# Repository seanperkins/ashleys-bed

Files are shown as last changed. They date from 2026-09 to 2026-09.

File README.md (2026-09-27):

# Ashley’s Murphy bed

Build guide: https://seanperkins.github.io/ashleys-bed/

Current design: Rockler I-Semble horizontal queen bed with one room-facing left bookcase and drawer. Overall carcass: **116¾ W × 64 H × 16 D inches**. The right cabinet is removed.

## Release status

The native models, drawings, parts list and nominal sheet layouts are design-review deliverables. **No machine-ready CAM or G-code is released.** Plywood and cutters have not been purchased. Final stock thickness, bookcase joinery, hardware, workholding, tools and the shop-approved post/profile must be resolved before machining.

Follow the complete [Rockler horizontal-bed instructions](https://go.rockler.com/tech/horizontal-murphy-bed-inst-25.pdf) and [HackRVA Avid PRO6096 requirements](https://wiki.hackrva.org/index.php/Avid_PRO6096). Hardware and motion in CAD remain representative. Hidden wall brackets remain required; both headboards and all specified anchors are retained.

## Fit allowances in the current design

These are built into the Fusion model, cut list, DXFs and drawings. They assume nominal stock; recheck them once the plywood is measured.

- **Adjustable shelves 1–3:** 15¾ × 28⅜ in, giving 1/16 in clearance per side between the bookcase's 28½ in sides so they can be placed on pins. The fixed shelf above the drawer stays 28½ in.
- **Bookcase back:** ¼ × 28 7/16 × 59 15/16 in, giving 1/32 in clearance per edge where it sits inside the carcass. Resize it if the back is set into rabbets or grooves instead.
- **Drawer box:** 27½ in wide in a 28½ in opening, ½ in per side for side-mount slides. Confirm against the chosen slide.
- **Gas springs (model only):** 14 in cylinder and 13½ in rod, chosen to span the modeled mounts. They are not Rockler's specification.

## Build the website

The website builder uses Python 3.10+ standard library only. No Node packages, API keys or backend are needed.

```sh
python3 site/build.py
python3 -m http.server 8047 --directory site/_site
```

Open http://localhost:8047. The build checks local links, anchors, duplicate IDs, required downloads and the current model revision. Page links are relative, so the guide works under the GitHub Pages project path.

- `site/content/`: page-specific instructions.
- `site/assets/`: responsive/print styles and browser-local checklist/worksheet behavior.
- `site/assets/vendor/`: pinned, self-hosted `<model-viewer>` 4.3.1 for the overview page's 3D viewer. No third-party requests.
- `site/build.py`: page shell, live BOM table, download index and explicit public-file allowlist.
- `output/`: current verified models and generated project documents.
- `.github/workflows/pages.yml`: builds and deploys the guide on pushes to `main` or manual dispatch.

Checklist and worksheet values remain in the reader’s browser. “Export my notes” downloads them; they are not sent to GitHub or a server. Printed worksheets expand full field values and disclosure notes. Checking boxes does not release machining.

## Update the design documents

1. Run `MurphyBedQueen/MurphyBedQueen.py` inside Autodesk Fusion. It creates a new design and exports open/closed F3D and STEP files, native previews, the wood cut list, drawing-body bounds and a build report. On success, `output/build-result.json` reports `"status": "exported; requires visual review of saved previews"` and an empty `timelineWarnings` list. Use any one of these:
   - **Fusion UI:** Utilities → Scripts and Add-Ins → Scripts → **MurphyBedQueen** → Run.
   - **Fusion MCP add-in (no clicks):** with the `AutodeskFusionMCP` add-in running, Fusion serves MCP at `http://127.0.0.1:8765/mcp`. Initialize a session, then call its `execute_python` tool with:

     ```python
     import importlib.util
     from pathlib import Path
     path = Path('/Users/sean/sites/ashleys-bed/MurphyBedQueen/MurphyBedQueen.py')
     spec = importlib.util.spec_from_file_location('ashleys_bed_model', path)
     module = importlib.util.module_from_spec(spec)
     spec.loader.exec_module(module)
     module.run({})
     ```

     A full run takes about 15 seconds. The script opens no dialogs, so it does not block Fusion's main thread.
   - **Startup add-in:** the `AshleysBedStartup` add-in in Fusion's `API/AddIns` folder runs the script once when Fusion starts if its manifest has `"runOnStartup": true`. It resets the flag to `false` before running and records `started`, `finished` or `failed` in `output/startup-trigger.json`.
2. Reopen both saved Fusion archives and verify the intended cabinet count/position, bed endpoints, required hidden references and timeline health. Review native previews; do not treat a successful export as a fabrication release.
3. Generate the nominal layouts and design-review drawings:

   ```sh
   python3 MurphyBedQueen/generate_cut_layouts.py
   python3 MurphyBedQueen/generate_drawings.py
   ```

   Then build the GLB files used by the site's 3D viewer (needs `pip install cascadio trimesh`). It writes static closed/open models and an animated open/close model. It fails if any part does not match the bed and leg joints in `MurphyBedQueen.py`, if the STEP gas-spring mounts moved, or if the swing puts the leg through the mattress or below the floor:

   ```sh
   python3 MurphyBedQueen/export_web_models.py
   ```

   The cut-layout generator uses the standard library and rejects unexpected parts or dimensions. When a part size changes on purpose, update its approved size in `PART_SPECS` (and its sheet placement in `SHEET_PLAN` if it no longer fits) in `generate_cut_layouts.py`. The drawing generator requires Pillow and the macOS Helvetica font; it consumes native Fusion body bounds, not guessed image dimensions. Site deployment does not regenerate CAD or require Pillow.
4. Update purchasing instructions and the BOM when the design changes. Then regenerate the one-page printable store list, `output/store-shopping-list.pdf`, with `python3 MurphyBedQueen/generate_store_list.py` (requires Pillow and the macOS Helvetica font). It takes quantities from the BOM and fails if a BOM item is added or removed without updating its `ITEMS` table, or if the list no longer fits on one page. Recheck all sheet quantities, hardware requirements and finish allowances. Refresh the design-review ZIP from the matching current outputs; do not include old revisions or prior budgets. To rebuild it with the same file list:

   ```sh
   cd output && unzip -Z1 ashleys-bed-design-review.zip > /tmp/zip-list.txt \
     && rm -f /tmp/review.zip && zip -q -X /tmp/review.zip -@ < /tmp/zip-list.txt \
     && mv /tmp/review.zip ashleys-bed-design-review.zip
   ```
5. Run the website build, inspect desktop/mobile pages, exercise saved checklists/search/note export, and print a worksheet with long notes before publishing.

## Publication boundary

The Pages artifact contains six guide pages, static assets and explicitly selected current downloads. Old two-cabinet budgets, media and local revision archives are excluded. The manufacturer PDF is linked at its official source rather than republished. Local `references/`, `revisions/` and `output/previous-*` directories are ignored.

Historical Richmond supplier leads are dated and are not current prices or stock confirmations. No current project total or mattress purchase price is represented.

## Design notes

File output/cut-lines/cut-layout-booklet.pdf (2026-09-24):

# ASHLEY'S MURPHY BED + LEFT BOOKCASE

## S01 | 3/4 in stock | 48 x 96 in | 4 parts

### NOMINAL PLANNING OUTLINES - NOT CNC-READY

3/4 in edge margin | 1/2 in minimum part gap | Grain parallel to every part length
M03 | M04

L16
L05

Stock width 48 in / length 96 in Origin (0,0): lower-left stock corner

GRAIN +Y

### PARTS ON THIS SHEET

Dimensions in inches: width x length X / Y = lower-left nominal outline

M03 Bed top
16 x 85 1/4 in
Finished thickness: 3/4 in X 0.75 / Y 0.75

M04 Bed bottom
16 x 85 1/4 in
Finished thickness: 3/4 in X 17.25 / Y 0.75

L16 Drawer face
10 1/2 x 28 1/4 in
Finished thickness: 3/4 in X 33.75 / Y 0.75

L05 Recessed plinth
2 1/2 x 28 1/2 in
Finished thickness: 3/4 in X 44.75 / Y 0.75

SHARED STOCK
Left shelf
Main cabinet

Drawing scale: 1:14.4
US Letter; print Actual Size / 100%.
Use written dimensions, not a paper template.

M07 on S02: mill the 3/4 in stock blank to 5/8 in finished thickness.
Shelf/back fit included; finalize joinery, slides and measured stock before cutting.
No cutter compensation, holes, pockets or G-code. Confirm cutter, workholding and post. DXF: inches, closed PART_OUTLINES. Stock/margin/grain/labels are reference only.

SVG: full scale in inches, including a separate note area. PDF: reduced-scale planning booklet.

27 parts | 6 full 3/4 sheets + 1 half-inch 24x48 panel + 1 full quarter-inch sheet | No spare

## S02 | 3/4 in stock | 48 x 96 in | 3 parts

### NOMINAL PLANNING OUTLINES - NOT CNC-READY

3/4 in edge margin | 1/2 in minimum part gap | Grain parallel to every part length
M05 | M06

M07

Stock width 48 in / length 96 in Origin (0,0): lower-left stock corner

GRAIN +Y

### PARTS ON THIS SHEET

Dimensions in inches: width x length X / Y = lower-left nominal outline

M05 Upper headboard
16 x 85 1/4 in
Finished thickness: 3/4 in X 0.75 / Y 0.75

M06 Lower headboard
16 x 85 1/4 in
Finished thickness: 3/4 in X 17.25 / Y 0.75

M07 Permanent stop
3 x 56 in
Finished thickness: 5/8 in X 33.75 / Y 0.75

DEDICATED STOCK
Main cabinet

Drawing scale: 1:14.4
US Letter; print Actual Size / 100%.
Use written dimensions, not a paper template.

M07 on S02: mill the 3/4 in stock blank to 5/8 in finished thickness.
Shelf/back fit included; finalize joinery, slides and measured stock before cutting.
No cutter compensation, holes, pockets or G-code. Confirm cutter, workholding and post. DXF: inches, closed PART_OUTLINES. Stock/margin/grain/labels are reference only.

## S03 | 3/4 in stock | 48 x 96 in | 4 parts

### NOMINAL PLANNING OUTLINES - NOT CNC-READY

3/4 in edge margin | 1/2 in minimum part gap | Grain parallel to every part length
M01 | M02
L03 | L04

Stock width 48 in / length 96 in Origin (0,0): lower-left stock corner

GRAIN +Y

### PARTS ON THIS SHEET

Dimensions in inches: width x length X / Y = lower-left nominal outline

M01 Bed right side
16 x 64 in
Finished thickness: 3/4 in X 0.75 / Y 0.75

M02 Bed left side
16 x 64 in
Finished thickness: 3/4 in X 17.25 / Y 0.75

L03 Left bookcase top
16 x 28 1/2 in
Finished thickness: 3/4 in
X 0.75 / Y 65.25

L04 Left bookcase bottom
16 x 28 1/2 in
Finished thickness: 3/4 in
X 17.25 / Y 65.25

SHARED STOCK
Left shelf
Main cabinet

Drawing scale: 1:14.4
US Letter; print Actual Size / 100%.
Use written dimensions, not a paper template.

M07 on S02: mill the 3/4 in stock blank to 5/8 in finished thickness.
Shelf/back fit included; finalize joinery, slides and measured stock before cutting.
No cutter compensation, holes, pockets or G-code. Confirm cutter, workholding and post. DXF: inches, closed PART_OUTLINES. Stock/margin/grain/labels are reference only.

## S04 | 3/4 in stock | 48 x 96 in | 4 parts

### NOMINAL PLANNING OUTLINES - NOT CNC-READY

3/4 in edge margin | 1/2 in minimum part gap | Grain parallel to every part length
L01 | L02
L07 | L08

Stock width 48 in / length 96 in Origin (0,0): lower-left stock corner

GRAIN +Y

### PARTS ON THIS SHEET

Dimensions in inches: width x length X / Y = lower-left nominal outline

L01 Left bookcase left side
16 x 64 in
Finished thickness: 3/4 in
X 0.75 / Y 0.75

L02 Left bookcase right side 16 x 64 in
Finished thickness: 3/4 in
X 17.25 / Y 0.75

L07 Shelf above drawer
15 3/4 x 28 1/2 in
Finished thickness: 3/4 in
X 0.75 / Y 65.25

L08 Adjustable shelf 1
15 3/4 x 28 3/8 in
Finished thickness: 3/4 in X 17.25 / Y 65.25

DEDICATED STOCK
Left shelf

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

## S05 | 3/4 in stock | 48 x 96 in | 3 parts

### NOMINAL PLANNING OUTLINES - NOT CNC-READY

3/4 in edge margin | 1/2 in minimum part gap | Grain parallel to every part length
M08 | M09

L09

Stock width 48 in / length 96 in Origin (0,0): lower-left stock corner

GRAIN +Y

### PARTS ON THIS SHEET

Dimensions in inches: width x length X / Y = lower-left nominal outline

M08 Door panel 5.1
21 1/8 x 61 13/16 in
Finished thickness: 3/4 in X 0.75 / Y 0.75

M09 Door panel 5.2
21 1/8 x 61 13/16 in
Finished thickness: 3/4 in X 22.375 / Y 0.75

L09 Adjustable shelf 2
15 3/4 x 28 3/8 in
Finished thickness: 3/4 in X 0.75 / Y 63.0625

SHARED STOCK
Left shelf
Main cabinet

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

## S06 | 3/4 in stock | 48 x 96 in | 3 parts

### NOMINAL PLANNING OUTLINES - NOT CNC-READY

3/4 in edge margin | 1/2 in minimum part gap | Grain parallel to every part length
M10 | M11

L10

Stock width 48 in / length 96 in Origin (0,0): lower-left stock corner

GRAIN +Y

### PARTS ON THIS SHEET

Dimensions in inches: width x length X / Y = lower-left nominal outline

M10 Door panel 5.3
21 1/8 x 61 13/16 in
Finished thickness: 3/4 in X 0.75 / Y 0.75

M11 Door panel 5.4
21 1/8 x 61 13/16 in
Finished thickness: 3/4 in X 22.375 / Y 0.75

L10 Adjustable shelf 3
15 3/4 x 28 3/8 in
Finished thickness: 3/4 in X 0.75 / Y 63.0625

SHARED STOCK
Left shelf
Main cabinet

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

## S07 | 1/2 in stock | 24 x 48 in | 4 parts

### NOMINAL PLANNING OUTLINES - NOT CNC-READY

3/4 in edge margin | 1/2 in minimum part gap | Grain parallel to every part length
L13 | L14
L11 | L12

Stock width 24 in / length 48 in Origin (0,0): lower-left stock corner

GRAIN +Y

### PARTS ON THIS SHEET

Dimensions in inches: width x length X / Y = lower-left nominal outline

L13 Drawer back
8 x 26 1/2 in
Finished thickness: 1/2 in X 0.75 / Y 0.75

L14 Drawer inner front
8 x 26 1/2 in
Finished thickness: 1/2 in X 9.25 / Y 0.75

L11 Drawer left side
8 x 14 in
Finished thickness: 1/2 in X 0.75 / Y 27.75

L12 Drawer right side
8 x 14 in
Finished thickness: 1/2 in X 9.25 / Y 27.75

DEDICATED STOCK
Left shelf

Drawing scale: 1:7.2
US Letter; print Actual Size / 100%.
Use written dimensions, not a paper template.

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

## S08 | 1/4 in stock | 48 x 96 in | 2 parts

### NOMINAL PLANNING OUTLINES - NOT CNC-READY

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

L06

L15

Stock width 48 in / length 96 in Origin (0,0): lower-left stock corner

GRAIN +Y

### PARTS ON THIS SHEET

Dimensions in inches: width x length X / Y = lower-left nominal outline

L06 Bookcase back
28 7/16 x 59 15/16 in
Finished thickness: 1/4 in X 0.75 / Y 0.75

L15 Drawer bottom
14 x 27 1/2 in
Finished thickness: 1/4 in X 29.75 / Y 0.75

DEDICATED STOCK
Left shelf

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

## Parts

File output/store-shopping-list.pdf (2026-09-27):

# Ashley's Murphy bed - store shopping list

Queen horizontal bed (86-3/4 in) + left bookcase (30 in). Check each box as it goes in the cart.
Planning quantities from the project bill of materials. Confirm the slide model, pull centers and shelf pins against the build guide before buying hardware.
LUMBER - buy full sheets; do not have the store cut them (the CNC layout needs full sheets)
6 sheets 3/4 in plywood, 4 x 8 ft | Cabinet-grade, veneer core. No MDF, particleboard or melamine.
1 project panel 1/2 in plywood, 2 x 4 ft | For the drawer box. Cabinet-grade.
1 sheet 1/4 in plywood, 4 x 8 ft | Bookcase back and drawer bottom.
HARDWARE
1 pair 14 in drawer slides | Full-extension, side-mount, ball-bearing; needs 1/2 in per side.
20 shelf pins, 5 mm | Steel, flat or spoon style. 12 needed + spares.
3 black bar pulls, about 6 in centers | Two for the bed doors, one for the drawer. Check screws are included.
1 furniture anti-tip kit | For the bookcase, rated for wood studs. Extra to the bed anchors.
Optional: 4 connector bolt sets | Joins bed and bookcase sides (about 1-1/2 in total). Not a wall anchor.
FASTENERS, GLUE & SHIMS
100 #8 x 2 in wood screws | Wood or cabinet screws, not drywall screws.
50 fluted dowels, 3/8 x 1-1/2 in | Hardwood.
25 #8 x 1-1/4 in wood screws | Permanent stop.
50 #6 x 1-1/4 in wood screws | Drawer box corners.
25 #8 x 1 in washer-head wood screws | Drawer face.
100 #6 x 3/4 in pan or washer-head screws | Bookcase back and drawer bottom.
1 bottle wood glue, 16 oz | Interior PVA.
1 small bottle removable threadlocker | Blue / removable strength.
1 pack hard cabinet shims | Plastic or composite, not soft wood.
PAINT & FINISHING
1 quart paintable wood filler | Sandable; for plywood edges and screw holes.
1 gallon primer | Suited to plywood and the enamel you choose.
2 gallons navy cabinet enamel | Match #182B49; check a dried sample first.
Optional: 1 quart clear water-based finish | Drawer box only.
3 packs sandpaper: 120, 180, 220 grit | Match your sander.
Painting supplies | Brushes/rollers, tray liners, masking tape, drop cloth, rags.
TOOLS - only if you do not already have them
8 mm Allen key | Drives the threaded inserts. The kit does not include this size.
3/8 in doweling jig | For the cabinet dowel joints.
Drill bits | 5/64, 1/8, 5/32, 3/16, 13/64, 5/16, 3/8 and 27/64 in, plus a #8 countersink.
Clamps, square, level, stud finder | For glue-up and installation. Do not use an impact driver.
NOT FROM THIS STORE
Rockler I-Semble HORIZONTAL QUEEN bed kit Rockler only. Not a vertical kit.
Queen mattress (you supply) | 60 x 80 in, 10 in thick max, 132 lb max, not foam or very light.
CNC cutters and machine time | Through HackRVA; not a store purchase.

BEFORE CHECKOUT
Sheets lie flat, faces have no dents or splits, and edges show no large voids.
Measure one sheet of each thickness with calipers and write it down; it sets final joinery and fit. Pulls and slides: check the screws are in the package before leaving.

Full details: seanperkins.github.io/ashleys-bed/purchase.html

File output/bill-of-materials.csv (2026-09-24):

Group | Item | Buy_quantity | Unit | Specification | Where_used | Quantity_basis | Notes | Source
Main materials | Rockler I-Semble horizontal queen steel-frame Murphy bed kit | 1 | complete kit | HORIZONTAL mount; QUEEN 60 x 80 mattress; steel platform with 40 wood slats | Center bed | One kit | Exact horizontal-queen SKU not verified; do not substitute a vertical kit. Included hardware appears in the separate kit-inventory CSV. Confirm the noted manual discrepancies with Rockler. | https://go.rockler.com/tech/horizontal-murphy-bed-inst-25.pdf pp4-5
Main materials | 3/4-inch cabinet-grade plywood | 6 | 48 x 96 inch sheets | Veneer-core cabinet-grade plywood; no MDF/particleboard core | Main bed cabinet and four bed fronts; LEFT cabinet carcass, shelves and drawer face | Shared-sheet purchasing layout; 21 stock pieces total | 20 finished 3/4-inch pieces plus one stop blank to mill to 5/8 inch. Main: 11 stock pieces from S01/S02/S03/S05/S06; S02 dedicated. Left: 10 stock pieces from S01/S03/S04/S05/S06; S04 dedicated. Shared: S01/S03/S05/S06. Buy S01-S06 once total. 3/4-inch sheet-edge margins and 1/2-inch gaps; grain follows Length_in. No spare full sheet or minimum-sheet claim. See plywood-by-project.csv for every piece. | Project bed-plus-left-cabinet design
Main materials | 1/2-inch drawer-box plywood | 1 | 24 x 48 inch project panel | Cabinet-grade plywood; actual thickness must be measured | One LEFT drawer box; four panels | Shared-sheet purchasing layout; four pieces on S07 | Two 8 x 14 sides and two 8 x 26.5 front/back panels; total cut area 4.5 sq ft. Panel length 48 inches is parallel to part Length_in. Confirm project-panel availability; no full-sheet price fallback is assumed. | Project bed-plus-left-cabinet design
Main materials | 1/4-inch plywood | 1 | 48 x 96 inch sheet | Cabinet-grade plywood; actual thickness must be measured | One LEFT cabinet back and one drawer bottom | Shared-sheet purchasing layout; two pieces on S08 | One 28-7/16 x 59-15/16 back (1/32 in fit clearance per edge) and one 14 x 27.5 drawer bottom; total cut area 14.5102 sq ft. One-piece back sized to sit inside the carcass; resize it if it is rabbeted or grooved instead. Attachment details remain pending. | Project bed-plus-left-cabinet design
Main materials | Permanent-stop material | 0 | additional sheets | Finished 5/8 x 3 x 56 inches | Bed closed-position stop | Included in 3/4-inch sheet allocation on S02 | Mill the allocated 3/4-inch blank M07 on S02 to the required 5/8-inch finished thickness; do not install it at 3/4 inch. | https://go.rockler.com/tech/horizontal-murphy-bed-inst-25.pdf p6
Compatibility check | Queen mattress | 0 | purchase not included | 60 x 80 inches; at most 10 inches thick and 132 lb; no foam or very light mattress | Bed | One compatible mattress required; compatibility check only | Not a priced or assumed new purchase. Maximum dynamic moving load 395 lb; suggested dynamic weight 280-395 lb includes door panels, hardware, mattress and bedding. Confirm complete moving-assembly weight; 132 lb is a maximum, not a target or minimum. | https://go.rockler.com/tech/horizontal-murphy-bed-inst-25.pdf p3
Cabinet hardware | Drawer slides | 1 | pair | 14-inch full-extension side-mount ball-bearing slides; nominal 1/2-inch clearance per side; nominal 100-lb pair rating | One LEFT drawer | One modeled 14-inch drawer box | Exact slide model not selected. Confirm its actual clearance, depth, load-rating conditions and mounting pattern before cutting or drilling. | Project bed-plus-left-cabinet design
Cabinet hardware | Shelf pins | 20 | pins | 5 mm steel shelf supports with flat/spoon bearing surface | Three adjustable LEFT shelves | 12 required plus 8 spares; one 20-pin pack allowance | Four supports per adjustable shelf; fixed shelf above drawer does not use pins. Match future hole diameter, depth and edge distances to the actual pins; shelves are cut 28-3/8 in wide for 1/16 in clearance per side; pin holes remain unmodeled. Verify actual pack contents. | Project bed-plus-left-cabinet design
Cabinet hardware | Matching pulls | 3 | pulls with fixing bolts | Black bar pulls; approximately 6-inch centers to match representative model | Two bed pulls and one LEFT drawer pull | Three pulls required | Choose the actual center spacing before drilling. Obtain six matching machine screws sized for 3/4-inch panels; do not buy them twice if supplied with the pulls. Thread depends on selected pull; do not independently assume M4 or #8-32. | https://go.rockler.com/tech/horizontal-murphy-bed-inst-25.pdf p17; project drawer design
Cabinet hardware | Bookcase anti-tip restraints | 1 | complete restraint kit | Manufacturer-rated restraints compatible with wood studs and 3/4-inch plywood cabinet structure, with specified fasteners | One installation kit for the LEFT cabinet | One separate tall cabinet | This is ADDITIONAL to all required bed anchors. Installer must select and install a suitable restraint and any required backing/blocking; do not anchor only to the 1/4-inch back. Restraint is not yet modeled. | Project bed-plus-left-cabinet design
Fasteners and adhesives | #8 x 2-inch wood/cabinet screws | 100 | screws | Wood/cabinet screws, not drywall screws | Bed carcass and LEFT cabinet fixed-panel assembly | 32 bed screws exact; balance is a cabinet/spare package allowance | Bed count: 8 at the two headboard/top-bottom joints plus 24 at side-panel joints, per pp9-10. Remaining 68 are a retained package allowance, not a required cabinet count. Cabinet quantity depends on final dado/joinery detailing. | https://go.rockler.com/tech/horizontal-murphy-bed-inst-25.pdf pp7,9-10; project cabinet allowance
Fasteners and adhesives | 3/8 x 1-1/2-inch dowels | 50 | dowels | Fluted hardwood joining dowels | Required bed-cabinet reinforced joints | 22 required; purchase allowance rounded to 50 | Six at headboard/top-bottom joints plus sixteen at side joints. These do not replace shelf pins. | https://go.rockler.com/tech/horizontal-murphy-bed-inst-25.pdf pp7,9-10
Fasteners and adhesives | #8 x 1-1/4-inch wood screws | 25 | screws | Wood screws suitable for the permanent stop | Bed permanent stop | At least 4 required; purchase allowance rounded to 25 | Not supplied in kit. Do not omit these simply because they are absent from the p7 shopping illustration. | https://go.rockler.com/tech/horizontal-murphy-bed-inst-25.pdf p18
Fasteners and adhesives | #6 x 1-1/4-inch wood screws | 50 | screws | Pilot-drilled wood screws for 1/2-inch plywood box corner joints | One LEFT drawer box | Retained 50-screw package allowance, not minimum or final fastener count | Final screw positions and need depend on drawer joinery; predrill to avoid splitting the thin plywood edges. | Project bed-plus-left-cabinet design
Fasteners and adhesives | #8 x 1-inch washer-head wood screws | 25 | screws | Washer-head wood screws; do not confuse with pull machine screws | Attach one false drawer front from inside box | 4 planned; purchase allowance rounded to 25 | Current inner front is 1/2 inch and false front 3/4 inch. Check actual stack and penetration before installation. | Project bed-plus-left-cabinet design
Fasteners and adhesives | #6 x 3/4-inch panel-attachment screws | 100 | screws | Pan/washer-head wood screws | One LEFT cabinet back and drawer bottom where final joinery provides backing | Retained 100-screw package allowance, not minimum or final fastener count | Only fasten where a completed rabbet, groove or suitable backing supports the joint. Back/bottom joinery is pending; this row is not a fastening layout. | Project bed-plus-left-cabinet design
Fasteners and adhesives | Slide mounting screws | 0 | extra packs if supplied with slides | Use fasteners specified by the selected slide manufacturer | One slide pair | Inventory check; about 12 screws reserved in assembly planning | Final required count comes from the selected slide manufacturer, not this allowance. If not supplied, obtain the specified set before assembly. For 1/2-inch drawer walls, do not use screws long enough to protrude; #6 x 1/2-inch pan-head is a candidate only if approved for the selected slides. | Project bed-plus-left-cabinet design
Fasteners and adhesives | Wood glue | 1 | 16 fl oz bottle | Interior woodworking PVA glue suitable for plywood and hardwood dowels | Bed dowels, LEFT cabinet fixed joints and one drawer box | One shared bottle; package allowance | Glue bare wood, not finished surfaces. Keep adjustable shelves unglued. | https://go.rockler.com/tech/horizontal-murphy-bed-inst-25.pdf pp7,9-10; project cabinetry
Fasteners and adhesives | Removable threadlocker | 1 | small bottle | Removable thread-locking liquid suitable for M5 steel fasteners | M5 saddle-lock screws Z and nuts EE | One bottle; manufacturer recommendation | Use according to threadlocker directions; do not substitute adhesive in the plywood threaded-insert holes. | https://go.rockler.com/tech/horizontal-murphy-bed-inst-25.pdf p15
Installation | Noncompressible shims | 1 | pack | Cabinet-installation shims | Level/plumb the bed and LEFT cabinet | One shared pack; site allowance | Bed must meet Rockler flush-to-wall/bracket installation requirements. A qualified installer determines shim quantity and acceptable shimming and required fastener embedment. | https://go.rockler.com/tech/horizontal-murphy-bed-inst-25.pdf pp11-12
Finish | Paintable wood filler | 1 | quart | Sandable filler suitable for plywood edges, voids and screw holes | Navy-painted surfaces and exposed plywood edges | Shared finish package allowance | Filler is cosmetic, not structural. This plan uses filled/sealed painted edges rather than assuming extra edge-band thickness. | Project bed-plus-left-cabinet design
Finish | Compatible wood primer | 1 | gallon | Primer suitable for veneer-core plywood and selected cabinet enamel | Painted panels, cabinet back and exposed edges | 289.1689 sq ft / 350 sq ft per gallon x 1 coat = 0.8262 gallon; round to 1 gallon | Both faces plus all edges; main 188.9527 sq ft and left 100.2162 sq ft. Natural-finish drawer-box panels/bottom excluded. Check actual product coverage; keep glue surfaces bare and allow additional edge sealing if required. | Project bed-plus-left-cabinet design
Finish | Dark navy cabinet enamel | 2 | gallons | Durable cabinet/trim enamel; match approved #182B49 with a physical sample | Painted bed and LEFT cabinet | 289.1689 sq ft / 350 sq ft per gallon x 2 coats = 1.6524 gallons; round to 2 gallons | Color code describes the design, not a guaranteed paint formula. Verify the dry sample and chosen product coverage. Allowance is shared across both remaining assemblies, not a per-cabinet purchase. | Project bed-plus-left-cabinet design
Finish | Clear drawer-box finish | 1 | quart | Waterborne clear furniture finish compatible with plywood | One natural-finish drawer box and bottom | Retained optional package allowance | Optional if unfinished drawer boxes are preferred; do not coat slide bearing surfaces. | Project bed-plus-left-cabinet design
Finish | Sandpaper or sanding discs | 3 | packs | 120, 180 and 220 grit; one pack per grit, matched to sander | Surface and between-coat preparation | Shared consumable allowance | Follow the finish manufacturer sanding schedule; avoid sanding through face veneers. | Project bed-plus-left-cabinet design
Finish | Painting consumables | 1 | set | Suitable brush/rollers, tray liners, masking tape, drop cloth, lint-free cloths and label-specified cleanup supplies | Primer and finish application | Shared consumable allowance | Use application tools and PPE appropriate for the selected coatings. | Project bed-plus-left-cabinet design
Optional alignment | Cabinet connector fasteners | 4 | matched sets if used | Connector bolts/sleeve nuts sized for two measured plywood side panels, about 1-1/2 inches combined | Optional LEFT cabinet-to-bed alignment; one interface | Four optional sets; not structural restraint | Not a substitute for wall restraints. Confirm allowed placement with Rockler/installer, clear of all mechanism hardware, before drilling additional bed-cabinet holes. | Project bed-plus-left-cabinet design
Check tools before buying | Drilling and doweling equipment | 0 | buy only if unavailable | Drill; 3/8 doweling jig; bits 5/64, 1/8, 5/32, 3/16, 13/64, 5/16, 3/8, 27/64 inch; #8 countersink; depth stops; future 5 mm shelf-pin boring bit | Manual-specific pilot holes, dowels and shelf-pin work | Check owned/HackRVA tools | Some sizes are specified later in the instructions rather than on p7. Confirm actual stock and bit depth before boring. | https://go.rockler.com/tech/horizontal-murphy-bed-inst-25.pdf pp7-12,17
Check tools before buying | Assembly and installation tools | 0 | buy only if unavailable | 8 mm Allen key; 3/8 nut driver/socket; Phillips driver; clamps; square; level; stud finder; tape; rubber mallet; safe step stool | Cabinet and kit assembly | Check owned/HackRVA tools | Kit includes 4 mm and 5 mm Allen keys, not the 8 mm insert key. Do not use an impact driver. | https://go.rockler.com/tech/horizontal-murphy-bed-inst-25.pdf pp3,7-20
Check tools before buying | CNC and safety equipment | 0 | buy only if unavailable | HackRVA-approved cutters, collets and workholding; dust extraction; eye/hearing protection; coating-appropriate respiratory protection | Cutting, sanding and finishing | Check machine-operator requirements | Final CNC tooling, feeds/speeds, toolpaths, training and machine time are not covered by this purchasing list. | Project bed-plus-left-cabinet design

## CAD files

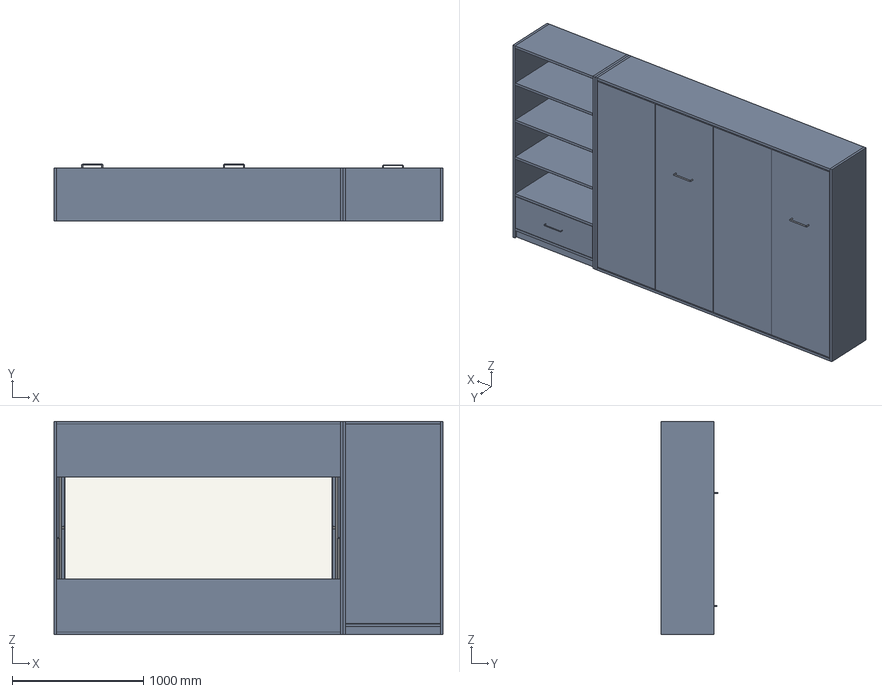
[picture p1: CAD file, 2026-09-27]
output/queen-horizontal-closed.step
2965.4 x 436.6 x 1625.6 mm

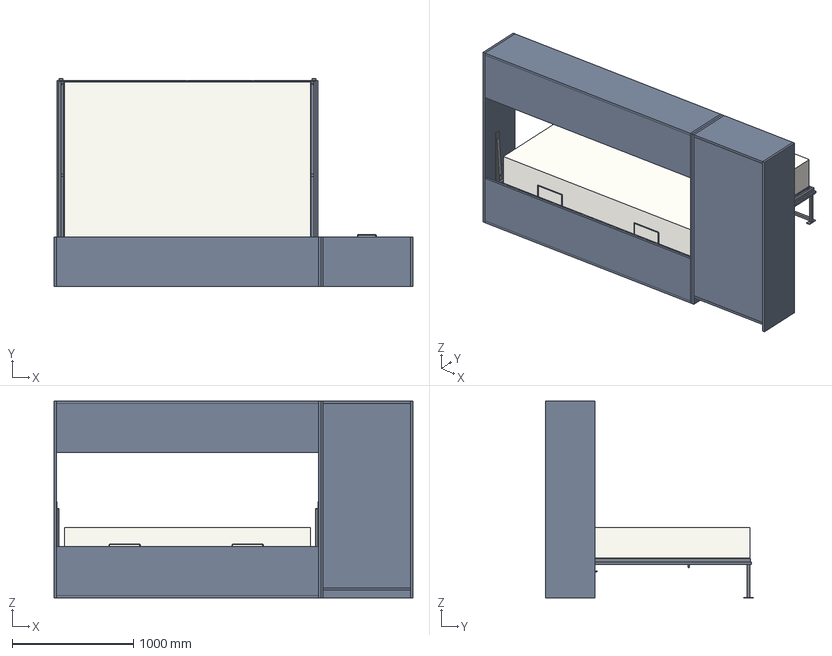
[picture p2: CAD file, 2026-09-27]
output/queen-horizontal-open.step
2965.4 x 1717.0 x 1625.6 mm

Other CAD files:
output/cut-lines/S03.dxf
output/cut-lines/S07.dxf
output/cut-lines/S08.dxf
output/cut-lines/S01.dxf
output/cut-lines/S02.dxf
output/cut-lines/S05.dxf
output/cut-lines/S06.dxf
output/cut-lines/S04.dxf
output/queen-horizontal-closed.f3d
output/queen-horizontal-open.f3d

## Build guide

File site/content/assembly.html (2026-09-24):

Use this as a build-stage checklist beside the complete Rockler instructions. Do not start fabrication until the planning decisions and machining inputs are resolved.

This is not a substitute for the manufacturer’s installation procedure. Read the entire manual before work. A qualified person must attach the bed to the wall, and another adult must help during installation. The mechanism can close suddenly without a mattress. Do not work alone, omit either headboard, substitute drywall anchors, or use an impact driver. Rockler safety warnings, p. 3 (https://go.rockler.com/tech/horizontal-murphy-bed-inst-25.pdf#page=3).

## Prepare the parts

### Stage 1 — Identify the kit and inventory everything

1. Confirm the actual kit is the horizontal queen version. Compare the supplied instructions with Rockler’s latest product instructions before using this February 2025 reference.
2. Lay out and identify the frame members, mounting plates, threaded inserts, pistons, legs, door brackets, mattress supports, 40 queen slats and all mounting hardware. Use the purchase guide to separate kit contents from additional purchases.
3. Resolve the manual’s conflicts with Rockler before substitutions: BB is listed as M8 × 45 mm on p. 5 but M8 × 50 mm on p. 13; W screw quantities differ between inventory and assembly text; four M6 nuts OO appear on p. 16 but not the inventory. Do not infer replacement fasteners.
4. Check tools, PPE, supported work surfaces, clamps, a square, a level, a suitable doweling jig, depth stops and safe access equipment. Follow each tool’s instructions and each coating’s safety data sheet.

Sources: Rockler pp. 2–3, safety (https://go.rockler.com/tech/horizontal-murphy-bed-inst-25.pdf#page=2); pp. 4–7, inventory, cabinet parts and tools (https://go.rockler.com/tech/horizontal-murphy-bed-inst-25.pdf#page=4); p. 13 (https://go.rockler.com/tech/horizontal-murphy-bed-inst-25.pdf#page=13) and pp. 16–18, conflicting fastener references (https://go.rockler.com/tech/horizontal-murphy-bed-inst-25.pdf#page=16).

### Stage 2 — Check stock, machine approved details and dry-fit

1. Measure actual plywood thickness and reject unsuitable or damaged stock. The bed cabinet requires suitable plywood, not MDF, particleboard or melamine-coated versions of those materials. Confirm the required interior opening against the actual kit.
2. Label all 27 parts with their sheet/part ID, assembly, inside face, front edge and grain direction. Follow the part-to-sheet map; shared sheets are not separate purchases for each assembly.
3. Use only the finalized machining plan. The available rectangular DXFs omit joinery, drilling and cutter compensation. A flat-sheet CNC setup does not automatically produce every edge-bored dowel or screw hole: an approved jig or separate documented setup may do that work.
4. Dry-fit the panels and inspect square, face orientation and joint seating before glue. Keep the bed’s Rockler dowel-and-screw construction unchanged; do not apply the proposed bookcase dados to the bed carcass.
5. Mill the allocated S02 stop blank to ⅝ × 3 × 56 in finished. Its final contact location is fitted later to the actual installed frame, not copied from the representative model.

Sources: Rockler p. 6, cabinet parts and opening (https://go.rockler.com/tech/horizontal-murphy-bed-inst-25.pdf#page=6); pp. 8–10, drilling and construction (https://go.rockler.com/tech/horizontal-murphy-bed-inst-25.pdf#page=8). Stock labels and CNC release checks are project workflow, not additional Rockler instructions.

## Build the two cabinets separately

### Stage 3 — Mount the plates and assemble the bed carcass

1. Follow the left/right drilling guide on p. 8 for the 16 threaded inserts and mounting plates. Confirm handedness and front-edge references before drilling. Use the specified inserts and M8 screws; ordinary wood screws are not an acceptable plate attachment.
2. Assemble the top/upper-headboard and bottom/lower-headboard pairs using Rockler’s dowel locations, hole depths, glue and screw procedure on p. 9. Together these joints require six dowels and eight #8 × 2 in screws.
3. Attach both side panels to those assemblies using the reinforced joints on p. 10: sixteen more dowels and twenty-four more #8 × 2 in screws. Clamp and check square as the joints come together; remove glue squeeze-out.
4. Verify the complete opening against the manufacturer’s requirement before continuing. Keep both headboards intact. Do not overtighten screws or conceal a damaged joint with filler.

Bed-carcass minimum: 22 hardwood dowels (⅜ × 1½ in) and 32 #8 × 2 in wood screws, plus wood glue. Purchase-pack leftovers are not a specified left-cabinet fastener schedule. Sources: Rockler p. 8 (https://go.rockler.com/tech/horizontal-murphy-bed-inst-25.pdf#page=8) and pp. 9–10 (https://go.rockler.com/tech/horizontal-murphy-bed-inst-25.pdf#page=9).

### Stage 4 — Build the left cabinet only after its joinery is approved

Fabrication hold: the custom left cabinet is not covered by the Rockler manual. Shallow dados/rabbets for fixed parts are proposed, but their widths/depths, resulting part lengths, back attachment, drawer-bottom support and fastener layout are not finalized. Do not cut those features from the nominal model.

1. The owner and fabricator must approve fixed top/bottom/shelf joinery and the back/plinth details using measured stock. Dry-fit the carcass square and verify supported fastening locations before glue-up.
2. Keep the three upper shelves adjustable. Choose the actual 5 mm pins, define their bore diameter/depth/edge distances. The three shelves need 12 supports. They are cut 28⅜ in wide, 1/16 in clearance per side between the 28½ in sides; recheck the fit on measured stock.
3. Select the exact 14 in slide pair before sizing or drilling the drawer. Verify its required side clearance, mounting pattern and compatible screws; the modeled ½ in-per-side clearance is only nominal. Confirm drawer joints, bottom support and false-front screw penetration against the real stack.
4. Fit the drawer, false front and pull after the cabinet is square. Keep glue off adjustable parts and prevent screws from protruding through thin drawer walls.

Project basis: current nominal cabinet cut list and hardware requirements. The selected slide, shelf-pin and restraint manufacturers’ instructions must supply the missing hardware-specific details; no model has yet been selected to cite.

### Stage 5 — Prepare and finish the wood

1. Trial-fit hardware first. Fill cosmetic defects and sand without cutting through face veneers. Follow the chosen finish system’s preparation and dust-removal instructions; filler does not repair a structural joint.
2. Mask bare glue surfaces wherever finishing precedes assembly. Protect mounting interfaces and moving hardware from coating buildup; do not paint slide bearing surfaces.
3. Approve a dried sample of the design navy, #182B49. Apply the selected compatible primer and cabinet enamel according to their labels, including drying, sanding, recoating and full-cure requirements.
4. Plan one primer coat and two finish coats over about 289.2 sq ft of painted faces and edges. At the planning coverage of 350 sq ft/gallon, this allows one gallon primer and two gallons enamel. Actual coverage, edge sealing and extra coats can increase use.
5. Leave the drawer-box walls and bottom natural or use the optional compatible clear finish. These five pieces are excluded from the navy-paint area. Allow finishes and glue to cure before loading and hardware adjustment.

Finish quantities are project allowances, not Rockler specifications. Follow the selected product label and SDS; Rockler p. 2 (https://go.rockler.com/tech/horizontal-murphy-bed-inst-25.pdf#page=2) requires chemical/tool safety practices, and p. 10 (https://go.rockler.com/tech/horizontal-murphy-bed-inst-25.pdf#page=10) discusses concealing cabinet screw holes.

## Anchor before installing the loaded mechanism

### Stage 6 — Install all headboard anchors and all three wall brackets

1. Have the qualified installer and adult helper move the bed cabinet into position. Resolve base molding, level and plumb it, and establish flush contact as required by pp. 11–12.
2. Locate at least three 2 × 4 or larger wooden studs. Install six of the supplied ¼ × 3 in lag bolts through the upper/lower headboards into those studs using the manufacturer’s layout and pilot-hole procedure.
3. Install all three top wall brackets HH at actual stud locations, flush to the wall and cabinet top. Follow every dowel, through-bolt and screw step on p. 12: the remaining six lag bolts anchor the brackets to the studs; three through-bolts II and six washer-head screws JJ secure the bracket/top connections.
4. Inspect the complete anchoring system: 12 lag bolts total, both headboards, three top brackets. The model hides the brackets only for presentation. Do not omit hardware or replace stud fastening with drywall anchors.
5. Install the left cabinet’s separate rated restraint using its manufacturer’s instructions and suitable structure. Do not rely only on the ¼ in back. Optional cabinet connector bolts align the cabinets; they do not restrain either cabinet against tipping.

Stop if the wall or flush-contact requirements cannot be met. The installer must resolve the condition with Rockler, not improvise an anchor substitution. Do not unscrew the bed cabinet from the wall once pistons are installed. Sources: Rockler pp. 11–12 (https://go.rockler.com/tech/horizontal-murphy-bed-inst-25.pdf#page=11); p. 14 (https://go.rockler.com/tech/horizontal-murphy-bed-inst-25.pdf#page=14).

## Follow the manufacturer’s mechanism sequence

Keep the actual manual open at the named pages. The stages below identify order and inspection gates, not replacement instructions for piston mounting, pivot retention or frame handling.

### Stage 7 — Assemble the steel frame and initial slats

Follow Rockler p. 13 (https://go.rockler.com/tech/horizontal-murphy-bed-inst-25.pdf#page=13) for frame orientation, support tabs and the exploded assembly. Resolve BB fastener length with Rockler first. Leave fasteners loose until the frame is assembled as directed, then tighten them. Install slats and caps per p. 14 (https://go.rockler.com/tech/horizontal-murphy-bed-inst-25.pdf#page=14), deliberately leaving the first and last rows out until the later step.

### Stage 8 — Fit pistons, retained pivots, temporary stops and legs

With the cabinet fully anchored and the adult helper present, follow pp. 14–16 (https://go.rockler.com/tech/horizontal-murphy-bed-inst-25.pdf#page=14) in their exact order: frame-side piston attachment; seating pivots in mounting-plate saddles; saddle locking plates and their fasteners; controlled frame positioning; cabinet-side piston attachment; temporary stops; then legs and foot bar. Follow the specified washers, locking nuts and recommended removable threadlocker at the saddle-lock fasteners. Resolve the OO nut inventory discrepancy before the foot-bar step.

Once the pistons are attached, the mechanism is under pressure. Do not release a pulled-down frame: it can snap upward. The bed will not stay down without a mattress. An adult helper must control it as instructed; do not stand on it without an adult holding it down. Do not detach the cabinet from the wall with pistons installed.

### Stage 9 — Fit and secure the four door panels

Use the queen bracket pattern and orientation in pp. 16–17 (https://go.rockler.com/tech/horizontal-murphy-bed-inst-25.pdf#page=16). Choose the actual pulls before drilling their fixing holes. Hang and adjust the four panels, then perform the manufacturer’s clearance check before permanent attachment: their outside edges must not contact the mounting plates or hardware, including when the legs are retracted and the bed is lowered beyond normal horizontal during that supervised check. Follow p. 18 (https://go.rockler.com/tech/horizontal-murphy-bed-inst-25.pdf#page=18) for final attachment and its prohibition on driving screws through the center frame support. Do not resolve the W screw-count discrepancy by guessing.

### Stage 10 — Fit the permanent stop and remaining supports

Follow pp. 18–19, Final Touches (https://go.rockler.com/tech/horizontal-murphy-bed-inst-25.pdf#page=18). Fit the ⅝ in-thick permanent stop centered and set back so the actual frame closes plumb. Secure it with at least four #8 × 1¼ in wood screws, not supplied in the kit. Install the mattress supports and the remaining first/last slat rows as directed. Maintain adult control of the unloaded frame throughout.

## Commission before normal use

Use Rockler p. 20 (https://go.rockler.com/tech/horizontal-murphy-bed-inst-25.pdf#page=20) for lowering the frame, deploying legs, loading the mattress with an adult helper and carefully closing it. The mattress must be 60 × 80 in, at most 10 in thick and 132 lb; foam or very light mattresses are prohibited. Confirm the full moving assembly—door panels, hardware, mattress and bedding—against p. 3 (https://go.rockler.com/tech/horizontal-murphy-bed-inst-25.pdf#page=3): maximum dynamic load 395 lb; suggested dynamic weight 280–395 lb. The 132 lb mattress limit is not a target or minimum. Mattress compatibility is retained without adding a mattress purchase or cost.

Installer sign-off: both headboards, all three top brackets and all 12 lag bolts are secure in verified wooden studs; cabinet is plumb and bracket contacts are flush. The left cabinet is separately restrained. Hardware check: pivots/locking plates, pistons, frame fasteners, legs/foot bar, door attachments, slats/caps and the permanent stop match the manufacturer’s instructions. All kit discrepancies are resolved. Supervised travel check: required door/hardware clearance is verified, legs support the lowered frame, the stop gives the correct closed position, and room circulation and moving-part clearance remain safe with the actual mattress/bedding. Before each operation: clear people and objects from the moving area; check for loose hardware, cabinet movement, damage or abnormal resistance. Stop use if anything is wrong and obtain qualified help. Never let children play on the unit or operate it without adult supervision. Owner handoff: retain the current kit manual and hardware records, demonstrate controlled opening/closing and leg operation, and ensure every permitted user understands the manufacturer’s safety warnings.

Questions or conflicts: Rockler technical support, 1-800-260-9663 (manual p. 20). Open the complete official manual (https://go.rockler.com/tech/horizontal-murphy-bed-inst-25.pdf) and check Rockler (https://www.rockler.com/) for the current instructions for the exact kit.

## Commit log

2026-09-22 feat: publish bed and left-cabinet build guide
    [S01.dxf, S02.dxf, S03.dxf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]
2026-09-24 feat: add interactive 3D model viewer to the guide
    Convert the open/closed STEP exports to Y-up GLB files, serve them
    through a pinned self-hosted model-viewer on the overview page, list
    them as downloads, and include the latest Fusion re-exports.
    [queen-horizontal-closed.f3d, queen-horizontal-closed.step, queen-horizontal-open.f3d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]
2026-09-24 feat: animate the bed opening and closing in the 3D viewer
    Give the generator's gas springs a fixed cylinder and rod length so only
    the rod slides. Rebuild the web models from the STEP poses with verified
    bed and leg joints, add an animated open/close GLB, and drive it from a
    play button and position slider on the overview page.
2026-09-24 chore: regenerate outputs with fixed-length gas springs
    Fusion re-run of MurphyBedQueen.py with the fixed cylinder/rod lengths.
    Rebuild the web models, design drawings and design-review ZIP from the
    new STEP/F3D exports.
    [queen-horizontal-closed.f3d, queen-horizontal-closed.step, queen-horizontal-open.f3d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]
2026-09-24 fix: add shelf and back fit clearances to the bookcase
    Adjustable shelves 1-3 drop to 28-3/8 in (1/16 in per side) so they fit
    between the 28-1/2 in sides on pins; the back drops to 28-7/16 x 59-15/16
    in (1/32 in per edge). Rebuild the Fusion model, cut list, sheet layouts,
    DXFs, drawings, web models and review ZIP; update areas and docs. The
    README documents running the generator through Fusion and the fit
    allowances.
    [S01.dxf, S02.dxf, S03.dxf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]
2026-09-27 feat: add a printable one-page store shopping list
    Generate output/store-shopping-list.pdf from the bill of materials,
    grouped by store section with checkboxes. It fails if the BOM gains or
    loses an item without a store-list entry, or if it overflows one page.
    Link it from the purchase page and downloads, and add it to the review
    ZIP.
    [queen-horizontal-closed.f3d, queen-horizontal-closed.step, queen-horizontal-open.f3d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]
